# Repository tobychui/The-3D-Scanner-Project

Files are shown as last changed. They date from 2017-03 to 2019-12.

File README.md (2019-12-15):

# Low-Cost-3D-Sanner-Project
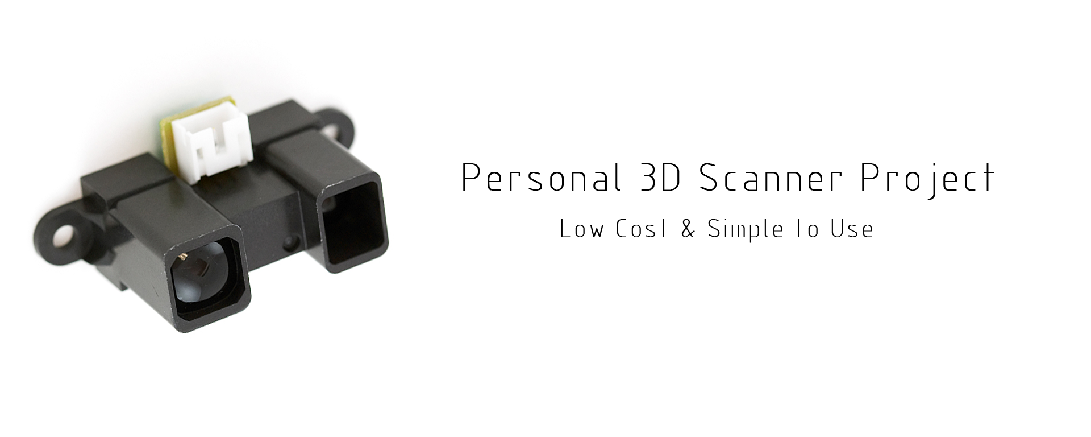
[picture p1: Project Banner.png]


This repo contains all the developmental data of creating a low cost 3D scanner with Arduino. Remember to read README before start building your own one as not all of the version will works.

* Each edition of the 3D Scanner might contain different license information. If a certain version of the scanner do not include a LICNESE file and/or information, the license in this directory (i.e. GNU License) will be used.

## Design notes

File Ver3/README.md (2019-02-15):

# Budget 3D Scanner Version 3

### Introduction
This is another 3D Scanner built with Arduino and Distance Sensor. Different from the other versions before, this version has a modular design and you can mount different type of sensor on the moving platform. 

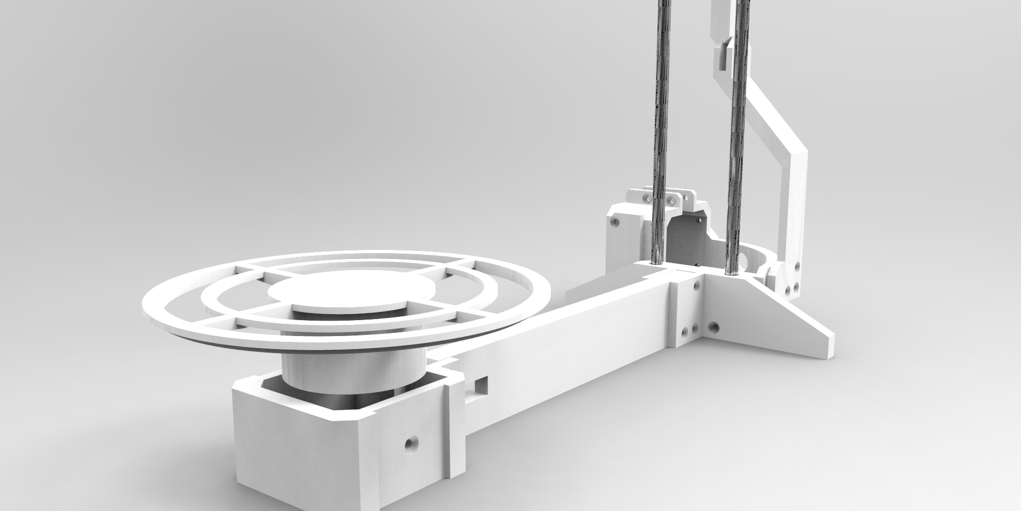
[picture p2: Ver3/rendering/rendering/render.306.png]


### How it works
There are two stepper motors in this device. One used for the platform rotation and one for movint the scanning platform up and down. The rotating platform will represent (and scan) the x / y location of the object while the another stepper will manage the sensor in z direction.

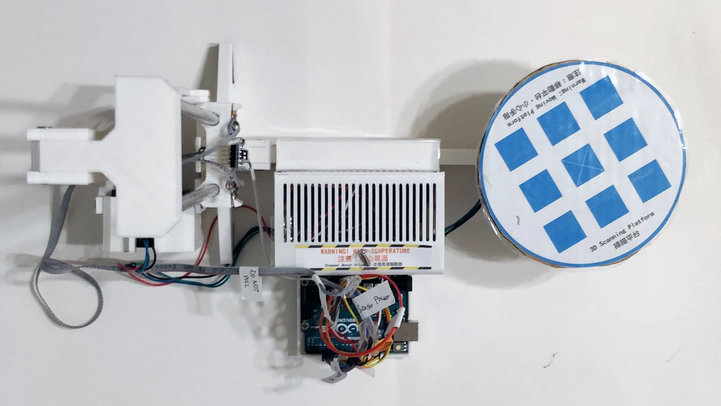
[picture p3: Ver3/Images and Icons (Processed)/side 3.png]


### Instllation & Build
1. 3D Printed all parts from the 3D Model folder. If the parts name is followed by a version number (e.g. parts ver2.stl), use the latest version instead.
2. Prepare the screws needed (All of them are M3 screws either M3 * 5, M3 * 10 or M3 * 20),screw in every screw holes on the 3D model as all of them are necessary.
3. Build the pully guider and glue the pully system in place to the body of the scanner with super glue
4. Install the end stop at the bottom of the devices where next to the bottom pully.
5. Flash in the Arduino code. Use ver 2.2 if you are using VL53L1X ToF Sensor or the infra edition if you are using SHARP IR Sensors
6. Insert all the stepper motor pins to the stepper driver (L298 * 2), and connect the stepper driver to the Arduino pins (4,5,6,7 and 8,9,10,11). Connect the ToF Sensor to SDA and SCL pins or the IR sensor to the A0 pins. End stop should be installed on Pin 12 and PULL LOW with a 10K Ohm resistor.
7. Plug in the power and do a test run. If everything is doing right, you can now install the stepper motors into the scanner body.
8. Use some imagination of anything didn't fits right :)

More details and scan results can be fnd in "Budget 3D Scanner Project.pdf" and operation video "quickdemo.mp4"

### Disclaimer
This project is developed by Toby (Me) and Andy, in which Andy was the guy who wrote the pos-processing scripts.
See his repo here:

<a href="https://github.com/tamyiuchau/Budget3dPrinter">https://github.com/tamyiuchau/Budget3dPrinter</a>

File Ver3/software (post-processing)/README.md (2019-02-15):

# Budget3dPrinter
This is a cheap low cost and might be kind of accurate 3D scanner instead of a printer

Yes, the title is fake. Same as the cake.

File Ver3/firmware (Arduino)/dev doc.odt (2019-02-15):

Budget 3D Scanner Operation Procedures and Documentation
Written by Toby Chui 2/2/2019, Corresponding Firmware: scanner_firmware_2.2

Introduction

This is a build for a low budget 3D scanner with ToF Sensor and Arduino UNO powered by dual 2.8V 200 steps per rev (1.8 degree) stepper motor driven with dual stepper motors. The driving methods and operating procedures is listed below.

Operating Procedures

1. Stick the object that you want to scan onto the platform with double sided tape
2. Plug in the USB cable for the Arduino Serial output to your PC
3. Start serial monitor / Python – Serial capture software
4. Power on the devices. The light blue LED should light up inside the enclosure
5. Run “G95”, wait for the scanner to reach its top position
6. Run “G97” when you place your hand in front of the scanner at a position > 6cm and < 20 cm. Check if the sensor return any value that is larger than 0. If not, continue step 7; otherwise go to step 8
7. Move around the “Sensor Power” wire. Press the restart button on the Arduino and repeat step 5
8. Run “G28”, wait for the sensor head reaching the bottom. If the motor is still running get stuck at the bottom, make sure the sensor wire is not blocking the contact between the head block and the micro switch below.
9. Now, it is ready to start scanning. Enter “G93” to start scanning. Scanning return value with format (h,r,d) where h is height in steps, r is rotation in steps, d is distance in mm.
10. Wait for the scanning process finish.
11. Power off the device after use to prevent heat accumulation in stepper driver

All Supported G-Code command

G28 → Sensor Home (Default)

G93 → Start Scanning

G94 → Calibration (Please put the calibration board in the center position of the scanner platform before using this command)

G95 → Sensor Home (Top), Moving the sensor to the top value preset)

G96 → Platform Check (Perform a full rotation as speed 60rpm)

G97 → Sensor Read (Get the current value from sensor)

DEFAULT → reply with “[info] Echo: <your command here>”

Firmware written for Budget 3D Scanner Project 2018 – 2019

DO NOT DISCLOSE BEFORE 15/2/2019

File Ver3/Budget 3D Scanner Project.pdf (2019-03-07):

# Budget 3D Scanner Project

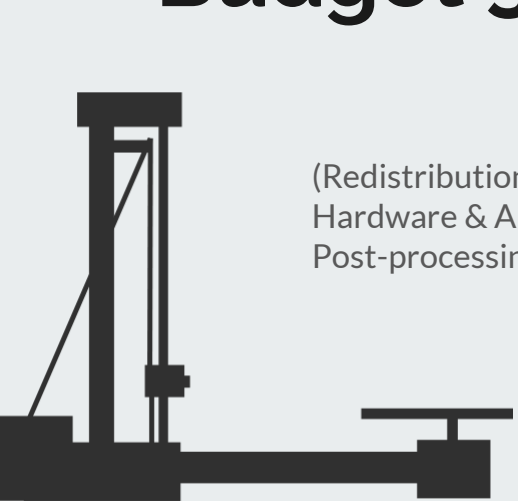
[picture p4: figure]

### (Redistribution Edition - Open Source Project) Hardware & Arduino Programming: Toby Post-processing & Optimization: Andy

# Introduction

- 3D Scanners are kind of expensive right now but it has a wide range of application
- We want to make a low cost 3D scanner with ToF Sensor and two stepper motors as Proof of Concept
- Aim as create somewhat observable 3D models from one single sensor by converting the sensor data into point clouds that construct the 3D model

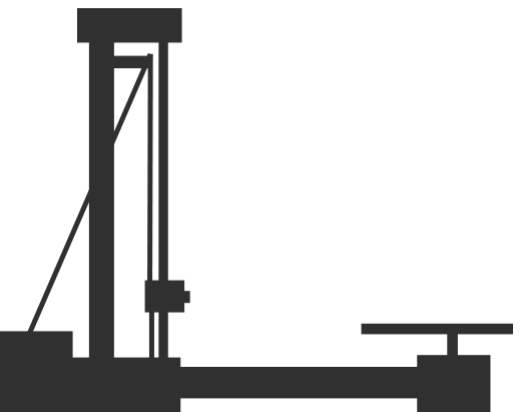
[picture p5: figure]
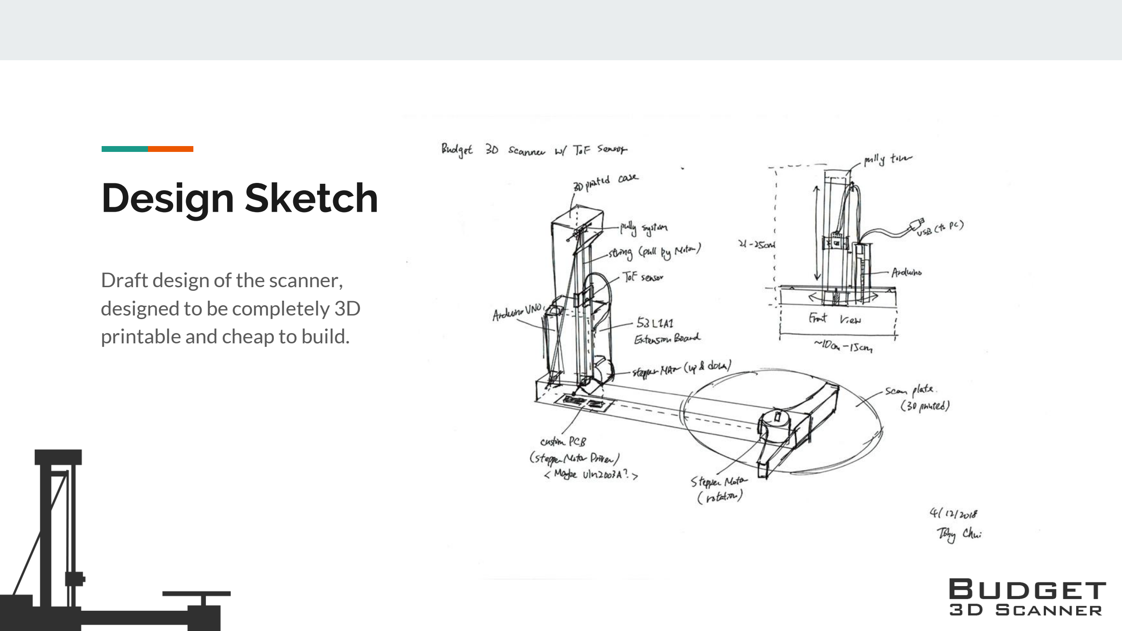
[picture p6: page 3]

# Design Sketch

Draft design of the scanner, designed to be completely 3D printable and cheap to build.

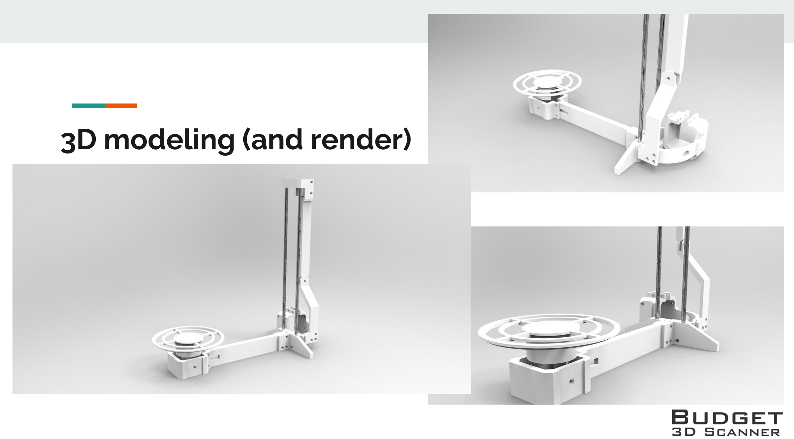
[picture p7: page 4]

# 3D modeling (and render)

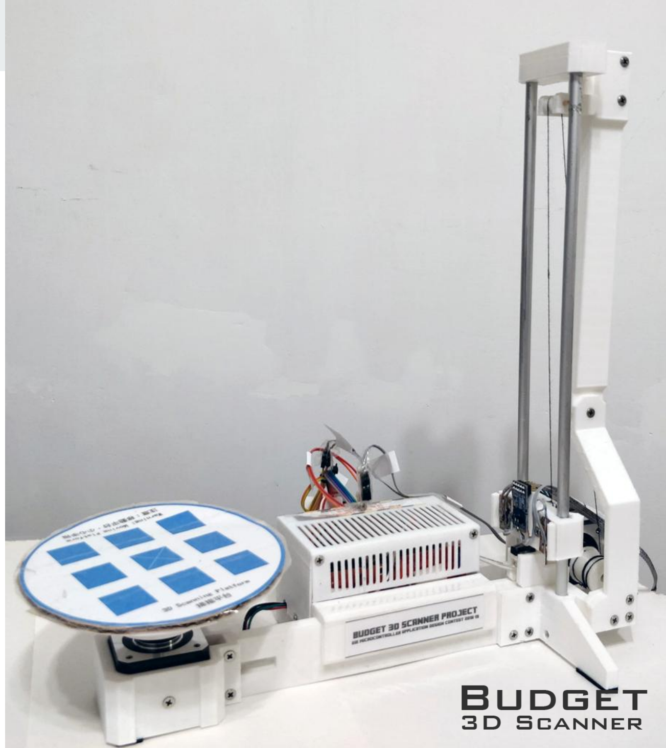
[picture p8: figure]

# Final Product (Scanner)

Specification:

VL53L1X ToF Sensor
(SHARP GP2D12F)
Arduino UNO
2.8V Stepper Motor x2
Many 3D Printed Parts

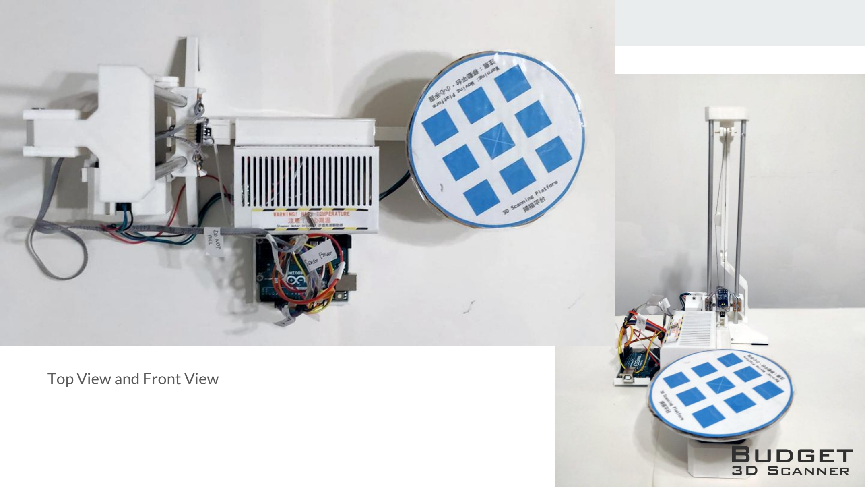
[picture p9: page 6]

Top View and Front View

# Scanner In Action

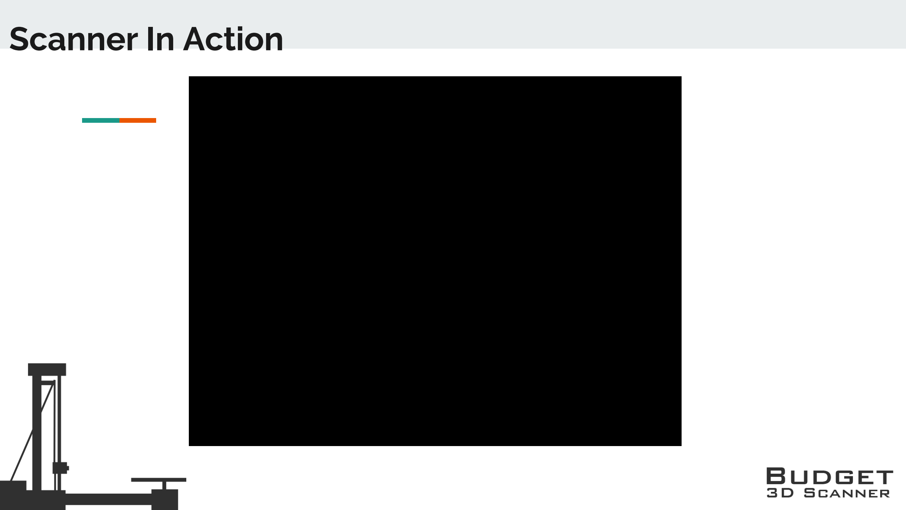
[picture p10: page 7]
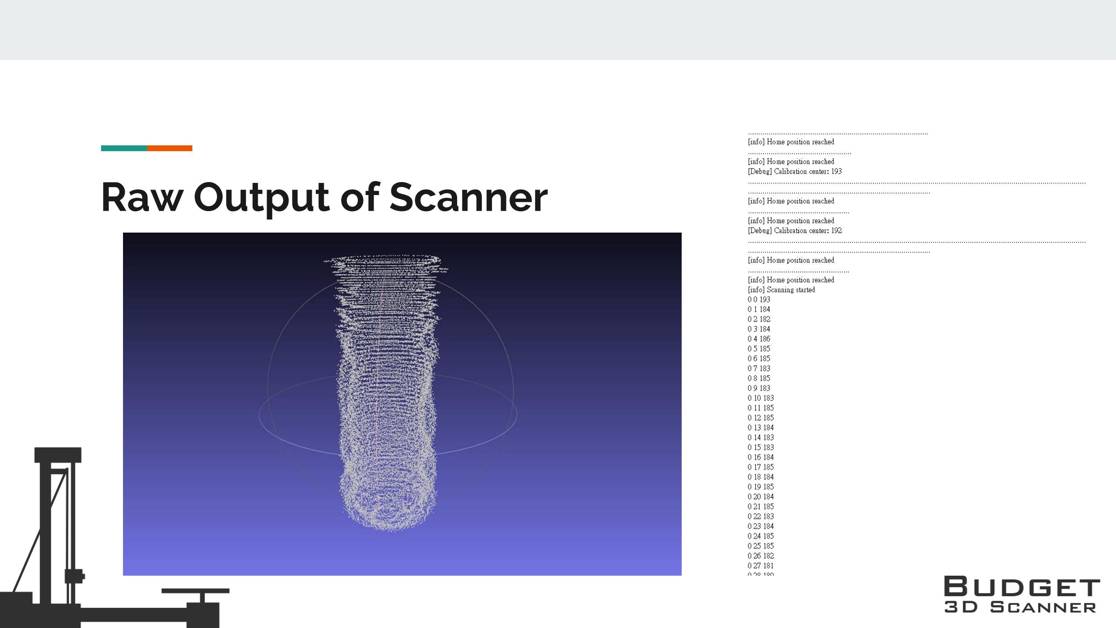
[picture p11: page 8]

# Raw Output of Scanner

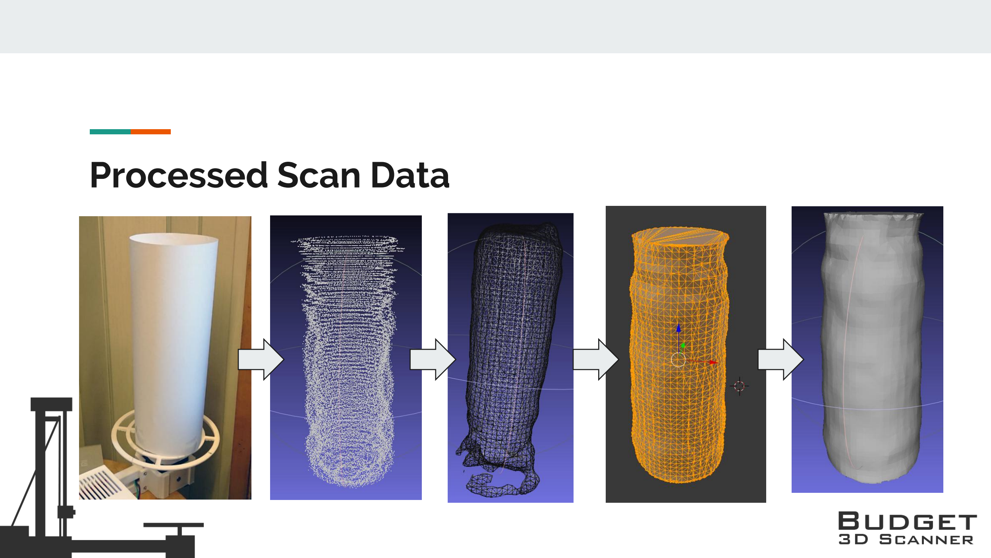
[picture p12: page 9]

# Processed Scan Data

# Calibration formula deduction

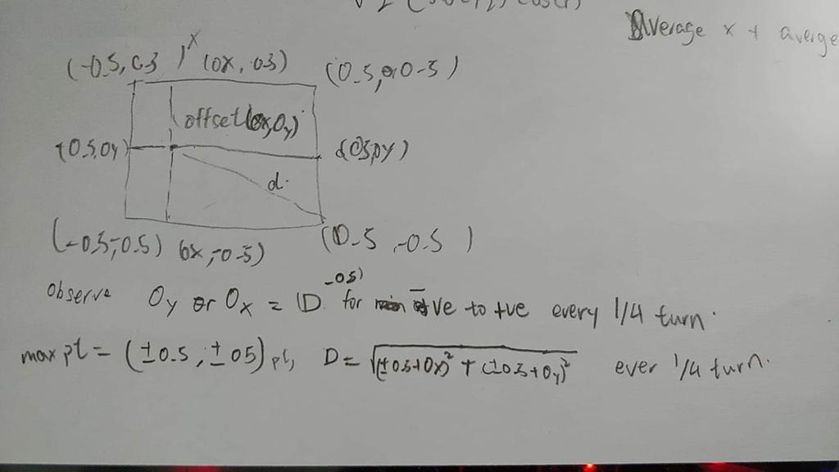
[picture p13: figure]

# Assumptions

The placement of calibration box is off centered → unknow center point

The height ratio is straight forward: (top - bottom )/ steps

The depth is the complicated part.

x = depth * sin(theta), y = depth * cos (theta)

But hey the box is off centered and we don’t know any of x and y and theta!

# Derive a function that link everything together

D =

(side /2 + Ox) / sin(theta+offset) | 0<= theta <=pi/2
(side /2 - Oy) / sin(theta+offset) | pi/2<= theta <= pi
(side /2 - Ox) / sin(theta+offset) | pi <= theta <= 3pi/2
(side /2 + Oy) / sin(theta+offset) | 3pi/2<= theta <= 2pi

Too complicate, we can go with only local minimum : (sin(theta)=1)

(Ox,Oy)

| D

# Going through the DARKNESS of calculus

We can eliminate variables using differentiation

d D/ dr = 0 ← solve r and left with 1 unknown

can be approximated by D(r+Δr)-D(r)/Δr

Also need to reject d^2 D/ dr > 0 (local max)

# It gots clear at this point

at each local minimum

d_min ± (Ox or Oy) = depth (measured by sensor)

One more trick

let Oy >= Ox

d - Oy <= d - Ox <= d + Ox <= d + Oy

cancel out Oy, done

(Ox,Oy)

| D

# Cost Summary

Item Name | Amount / Units | Cost (in HKD) | Remarks
3D Printed Parts | Around 700g | $84 | Estimated Material Cost
VL53L1X | 1 | $336 | Replaced with Infrared sensor due to accident
GP2D12 | 1 | $78 | SHARP Infrared sensor
L298N | 2 | $35.3 x 2
Arduino UNO | 1 | $180.52

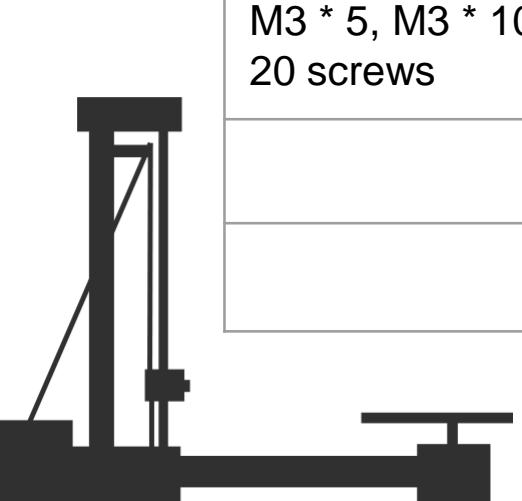
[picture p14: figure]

M3 * 5, M3 * 10, M3 * 20 screws | >20 | Neglectable
| | Total (with ToF) | $671.12
| | Total (with IR) | $413.12

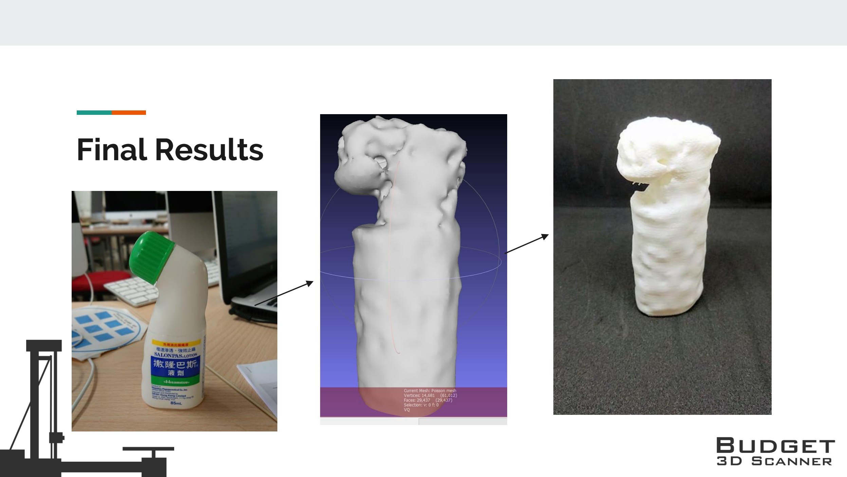
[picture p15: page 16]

# Final Results

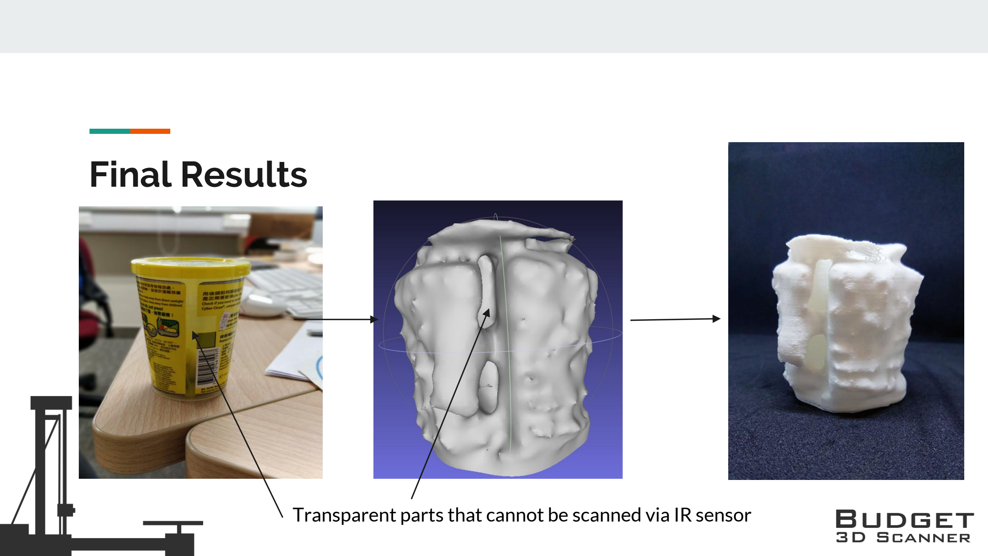
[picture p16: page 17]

# Final Results

Transparent parts that cannot be scanned via IR sensor

# Future Development

- Use dual sensor mode with Ultrasound Sensor to reduce error from reflection and transparent material
- Improve post-processing and scanning accuracy (This ToF Sensor is not the best one to suit this kind of application)
- 3D Copying Machine! (Scanner directly output gcode for 3D printer to print at the same time)

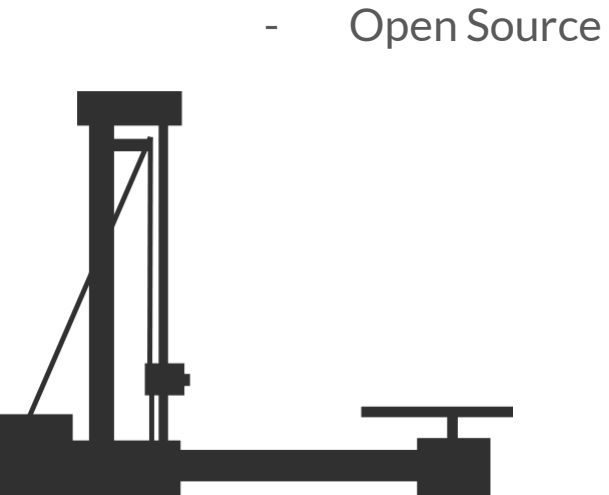
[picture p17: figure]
- Open Source
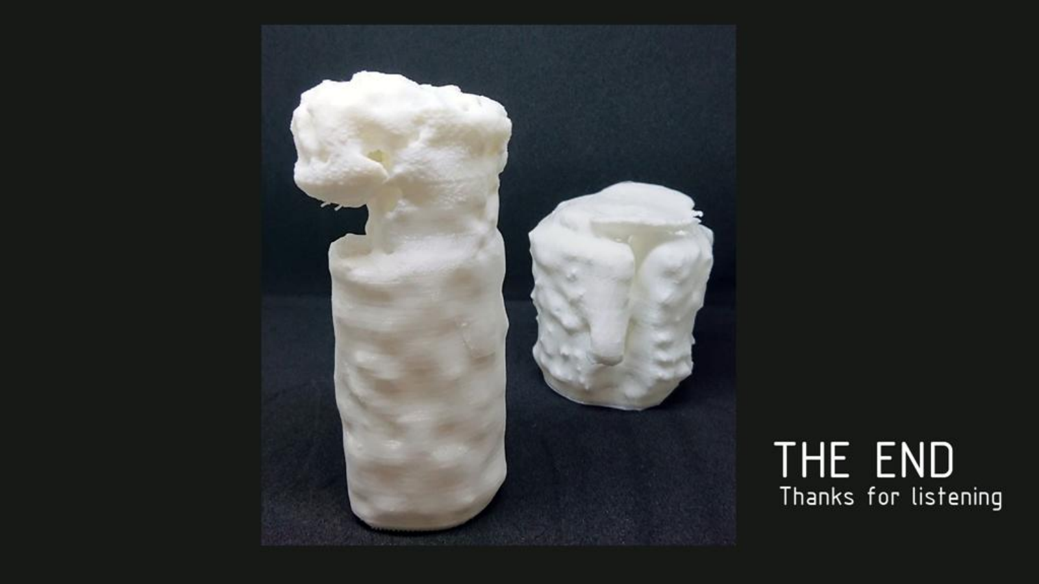
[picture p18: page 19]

# Thank you

# Reference and CopyRight

All the content in this powerpoint is licensed under IMUS License (Somewhat the same as MIT License with some extra about hardware), All Right Reserved.
You can freely distribute this powerpoint with the following restriction
- No Commercial Uses
- No charge / fees should be involved when distributing this powerpoint and related files inside this project
- Toby and Andy (Author of this project) has all right towards this project and all project material. The author will not bear any responsibility to the safety, workability, accuracy or other technical or safety related issue regarding this machine.
- Ask for permission for usage if you are using this project (and its material) for any purposes except educational and personal uses purpose.

Visit https://www.facebook.com/ImusLaboratory for more information

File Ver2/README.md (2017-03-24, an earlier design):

# 3D Scanner Ver 2

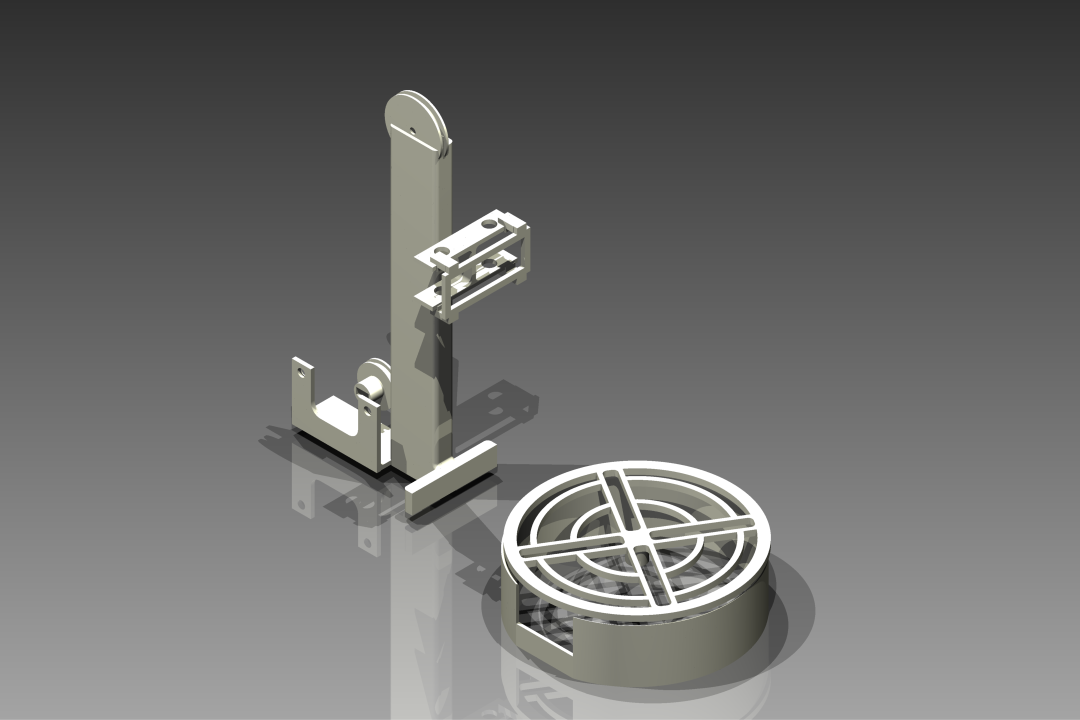
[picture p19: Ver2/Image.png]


This version is the 1st succeed version of the low cost 3D printer Project with ultrasound Sensor.
For the tutorial to make this scanner, please visit my instructable here:

https://www.instructables.com/id/Ultra-Low-Cost-3D-Scanner/

## Simple Instruction
To use this scanner, you have to build the 3D scanner itself with the 3d models provided here
Next, uplaod the Arduino sketch onto your arduino nano (Arduino UNO will work just fine)
Run the code using Arduino IDE Serial, copy all the returned information into the software "Length to 3D coordinate Scanner Data Convertor"
Convert it from raw information to coordinate data
Copy the exported data and sve them in a text file named "your name here".asc
Open that file in Meshlab for viewing

## How to convert it into stl?
To convert it into stl, you have to import the asc file into Meshlab
From filter, choose Calculate Normal with a sample rate 500 -1000 for the best results.
Next, also from the filter section, select Possion Surface Reconstruction (Or the reconstruction function with the name "Possion" in it if you are using newer version)
Click ok, wait for it and export the stl mesh as usual.

## How can I improve the accuracy of reading?
You can add one more line in the Arduino code to do the following things
1. For each point, scan multiple times and get the mean value of the reading
2. After reading a point, rotate smaller degree for more points (vertex) in 3D model
3. Change the Ultrasoud Sensor into Infrared Sensor (which someone already did) or laser distance sensor (which is very expensive)
4. Don't put in any soft item for scanning (e.g. cloth like materials, sponge, or things with a lot of holes)

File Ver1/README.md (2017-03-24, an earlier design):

# Version 1
This version of 3D Scanner make use of two stepper motors and one Ultrasound Sensor to scan the object in front of the scanner.
Please ** DO NOT USE THIS VERSION ** unless you are using those commercial printer with super high accuracy. 

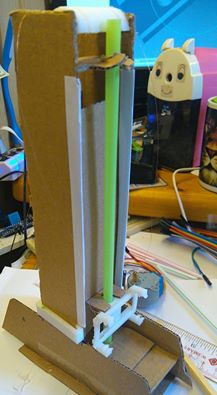
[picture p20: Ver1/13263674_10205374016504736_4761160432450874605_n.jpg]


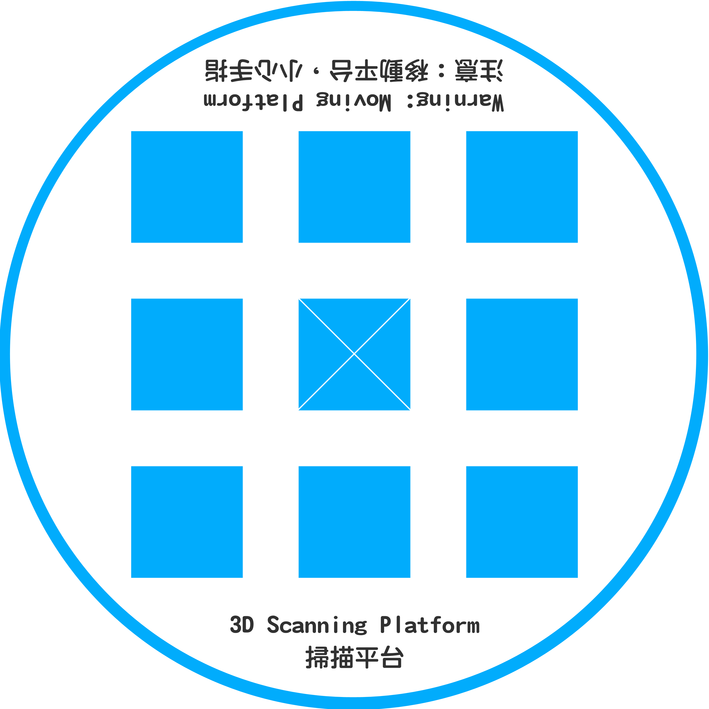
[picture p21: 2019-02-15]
Ver3/3D Models/platform and labels/platform label.png

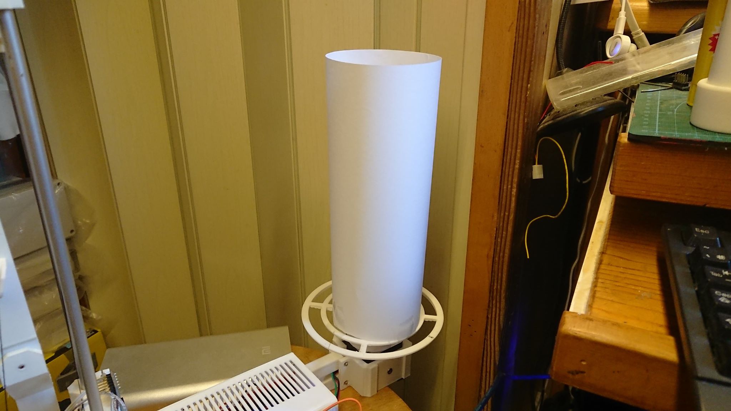
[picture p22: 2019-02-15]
Ver3/trial-scan data/post-processing/50949553_391221454968924_2815259296256753664_n.jpg

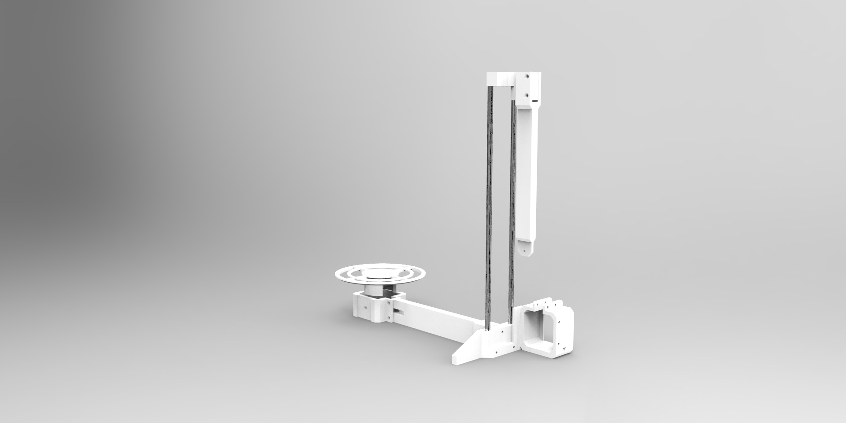
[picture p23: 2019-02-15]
Ver3/rendering/rendering/render.301.png

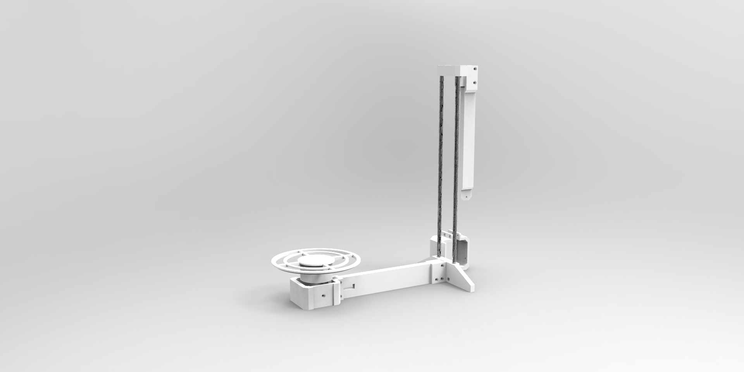
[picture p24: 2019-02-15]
Ver3/rendering/rendering/render.300.png

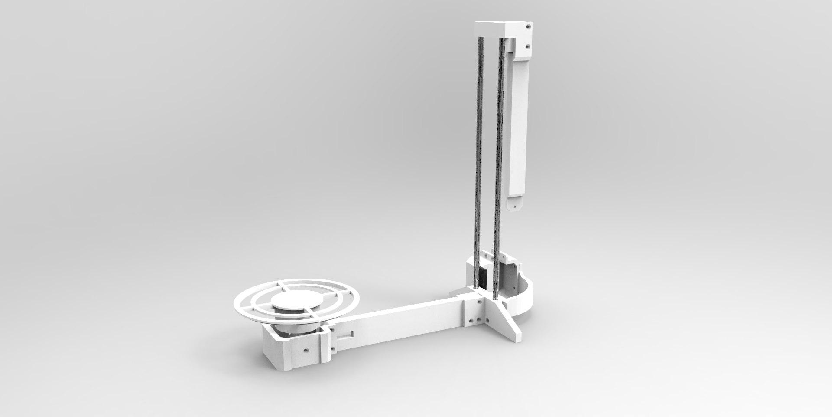
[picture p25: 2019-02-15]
Ver3/rendering/rendering/render.302.png

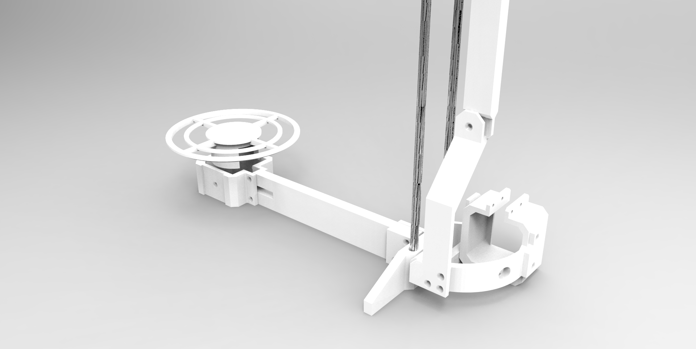
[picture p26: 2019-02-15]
Ver3/rendering/rendering/render.305.png

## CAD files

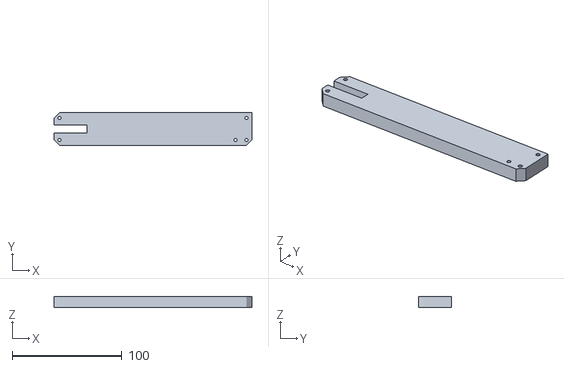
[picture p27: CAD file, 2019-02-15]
Ver3/3D Models/Connection Bar.stl
180.0 x 30.0 x 10.0

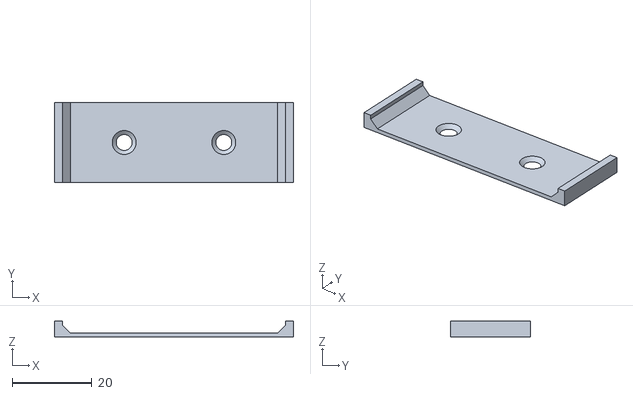
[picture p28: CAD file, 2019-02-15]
Ver3/3D Models/scanner head/head mount.stl
60.0 x 20.0 x 4.00

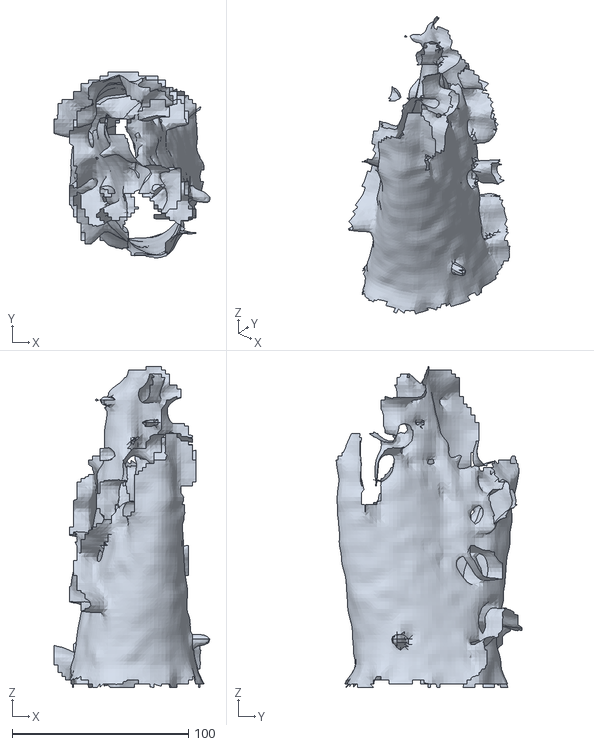
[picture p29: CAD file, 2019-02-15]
Ver3/trial-scan data/plymcout.ply
88.4 x 105.6 x 182.1

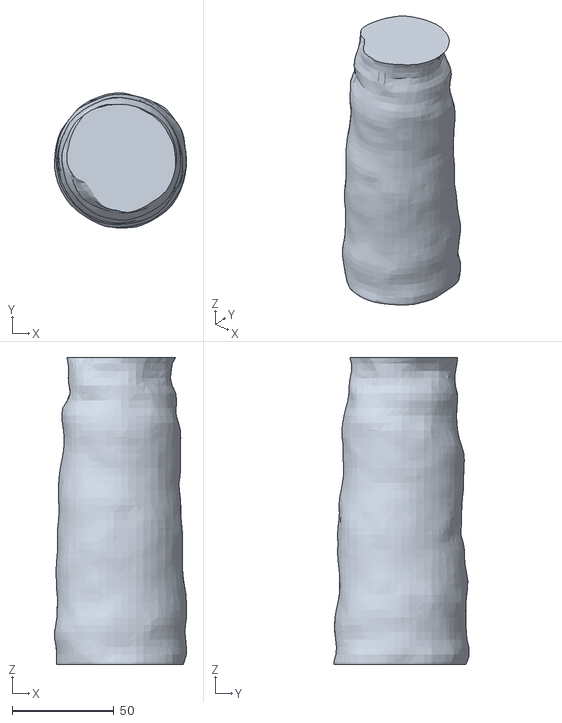
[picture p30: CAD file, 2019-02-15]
Ver3/trial-scan data/post-processing/scan log (after cropping).stl
65.0 x 66.5 x 150.9

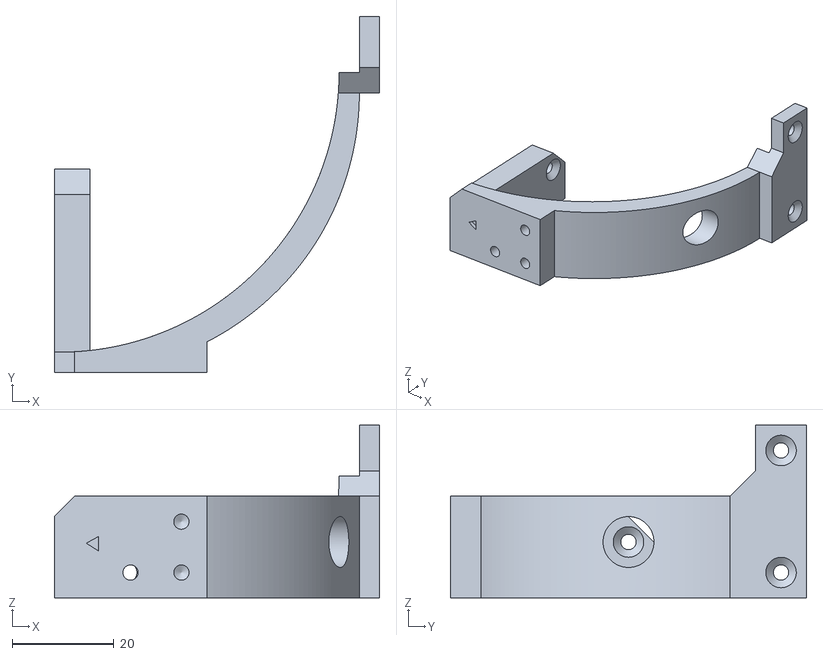
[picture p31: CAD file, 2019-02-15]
Ver3/3D Models/z-stepper support arm.stl
64.0 x 70.0 x 34.0

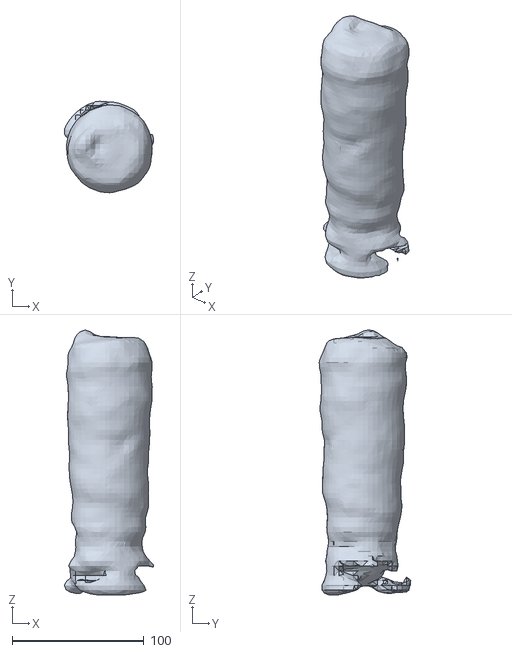
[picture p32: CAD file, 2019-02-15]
Ver3/trial-scan data/post-processing/scan log.stl
67.6 x 69.4 x 200.8

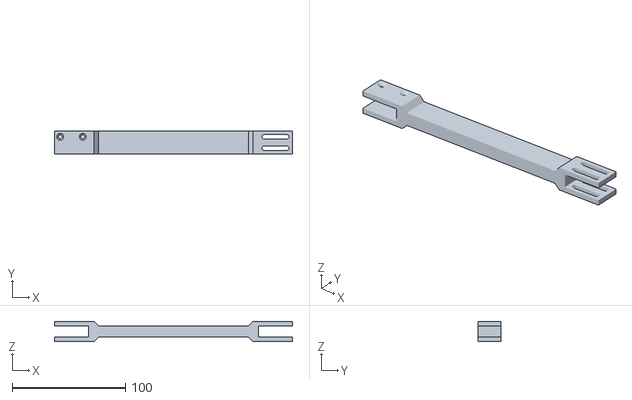
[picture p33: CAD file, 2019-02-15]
Ver3/3D Models/Upper Support beam.stl
210.0 x 20.0 x 18.0

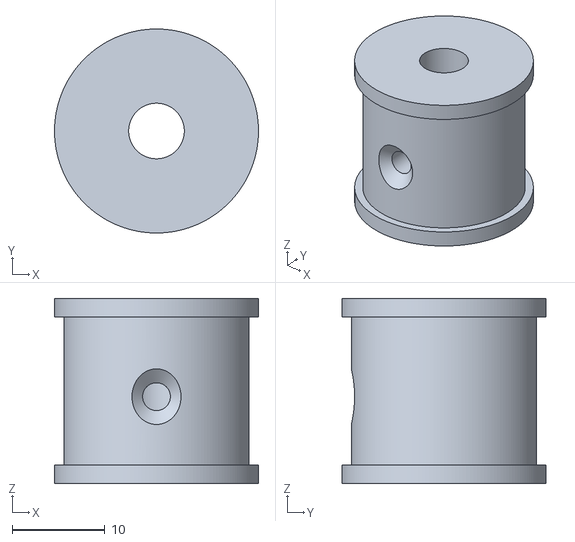
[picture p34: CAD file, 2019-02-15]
Ver3/3D Models/z-col pully sys/bearing v3.stl
22.0 x 22.0 x 20.0

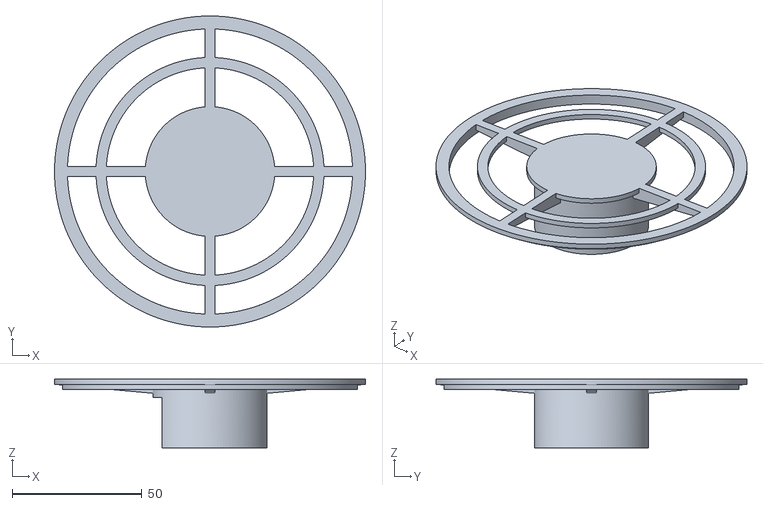
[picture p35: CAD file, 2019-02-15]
Ver3/3D Models/rotating platform.stl
120.0 x 120.0 x 26.5

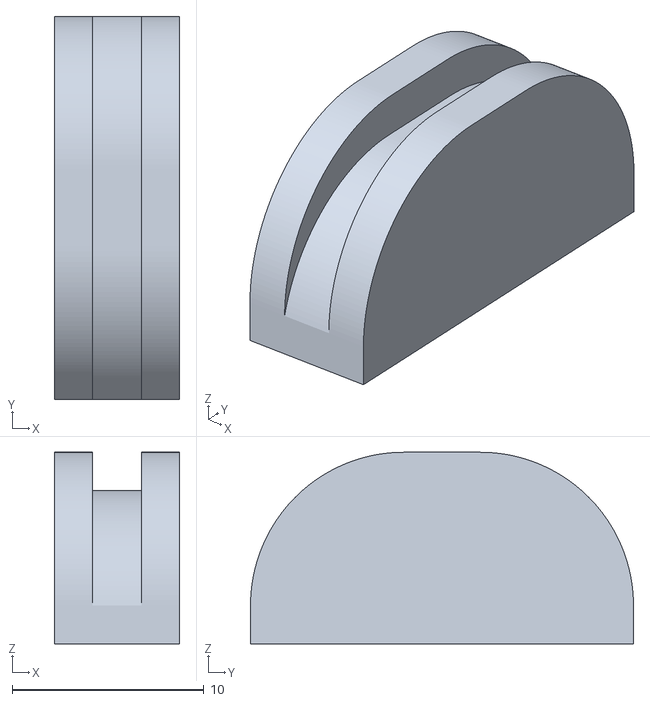
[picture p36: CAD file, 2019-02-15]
Ver3/3D Models/z-col pully sys/String Tightener.stl
6.55 x 20.0 x 10.0

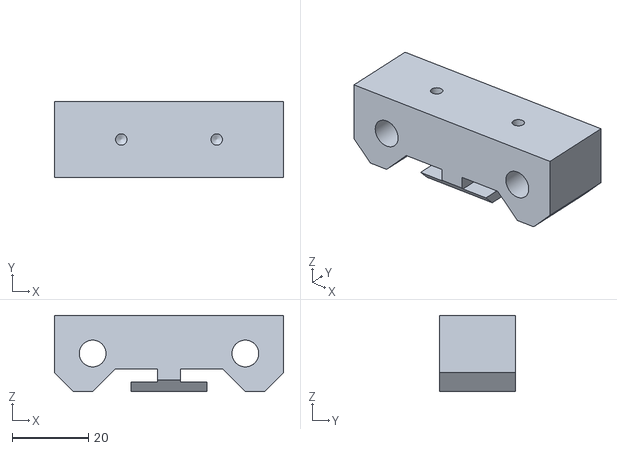
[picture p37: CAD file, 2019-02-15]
Ver3/3D Models/z-col pully sys/Moving block.stl
60.0 x 20.0 x 20.0

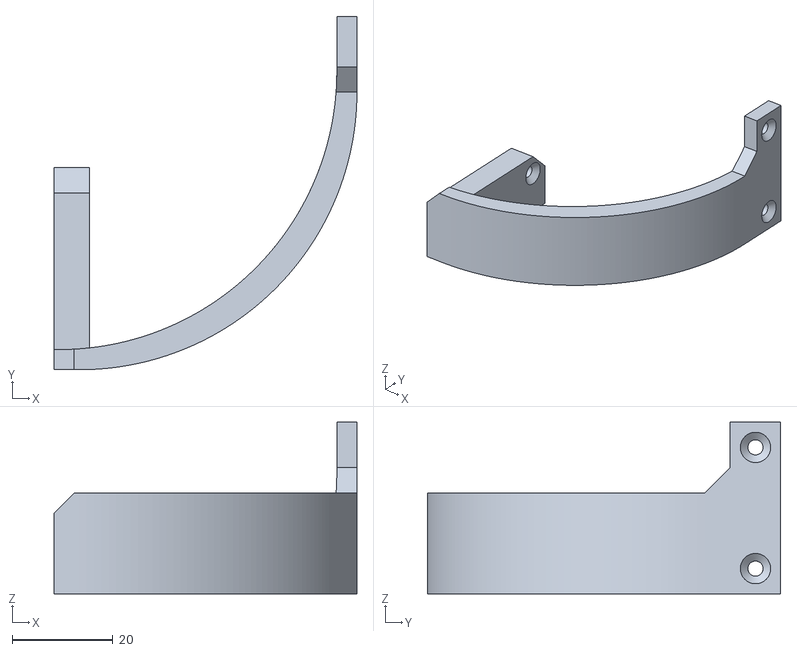
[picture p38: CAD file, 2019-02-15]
Ver3/3D Models/z-stepper support arm test2.stl
60.0 x 70.0 x 34.0

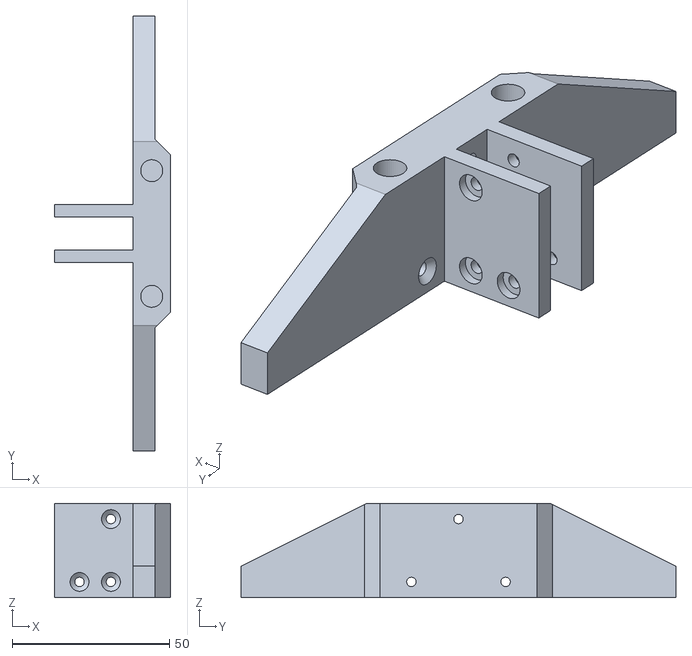
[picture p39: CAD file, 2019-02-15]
Ver3/3D Models/Col support beam.stl
37.0 x 138.5 x 30.0

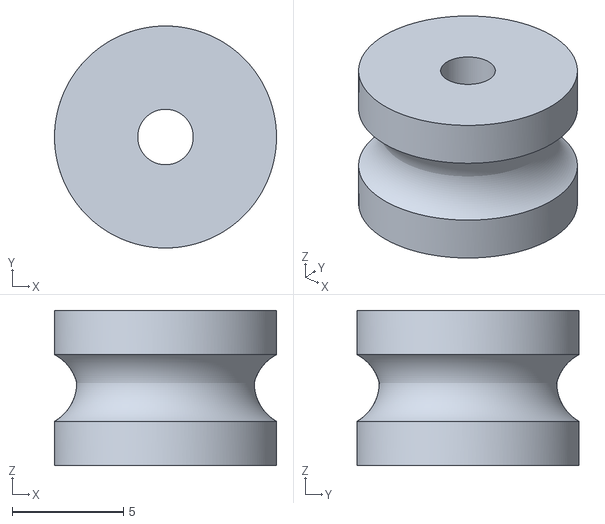
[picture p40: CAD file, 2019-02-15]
Ver3/3D Models/z-col pully sys/pully.stl
10.0 x 10.00 x 7.00

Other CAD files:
Ver3/trial-scan data/post-processing/scan log (subdivided).stl
Ver3/trial-scan data/post-processing/scan log (final).stl
Ver3/3D Models/col support base.stl
Ver3/3D Models/z-col pully sys/Bottom pully rack.stl
Ver1/Roller ver2.ipt
Ver1/Roller ver2.stl
Ver1/Roller.ipt
Ver1/Roller.stl
Ver1/Side Grapper.ipt
Ver1/Side Grapper.stl
Ver1/Slider.ipt
Ver1/Slider.stl
Ver1/Top Pully.ipt
Ver1/Top Pully.stl
Ver1/Up go er.ipt
Ver1/Up go er.stl
Ver1/baser.ipt
Ver1/baser.stl
Ver2/Cable Sliding Assistor.ipt
Ver2/Cable Sliding Assistor.stl
Ver2/Main Stand.ipt
Ver2/Main Stand.stl
Ver2/OldVersions/Slider.0001.ipt
Ver2/OldVersions/Top Holder.0001.ipt
Ver2/Pulling Stepper Pully.ipt
Ver2/Pulling Stepper Pully.stl
Ver2/Pully Top.ipt
Ver2/Pully Top.stl
Ver2/Scanning Disk.ipt
Ver2/Scanning Disk.stl
Ver2/Slider ver2.ipt
Ver2/Slider ver2.stl
Ver2/Slider.ipt
Ver2/Slider.stl
Ver2/Stpper Wheel 2.ipt
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

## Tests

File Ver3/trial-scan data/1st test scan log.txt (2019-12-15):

[info] Budget 3D Printer Control System
[info] Starting I2C connectons...
[info] Initializing VL53L1X sensor...
[info] VL53L1X initialized
[OK] Ready!
...................................................................................................................................................................................................................................
[info] Home position reached
[info] Scanning started
0 0 170
0 5 170
0 10 144
0 15 144
0 20 148
0 25 148
0 30 142
0 35 142
0 40 137
0 45 137
0 50 132
0 55 132
0 60 110
0 65 110
0 70 134
0 75 134
0 80 140
0 85 140
0 90 143
0 95 143
0 100 117
0 105 117
0 110 121
0 115 121
0 120 160
0 125 160
0 130 146
0 135 146
0 140 138
0 145 138
0 150 136
0 155 136
0 160 154
0 165 154
0 170 132
0 175 132
0 180 141
0 185 141
0 190 145
0 195 145
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
[info] Scanning Ended
...........................................................................................................................................................................................................................................................................................................................................................................................................................................................................................................................................................................................................................................................................
[info] Home position reached

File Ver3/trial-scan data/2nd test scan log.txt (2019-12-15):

0 0 232
0 1 232
0 2 232
0 3 232
0 4 232
0 5 232
0 6 157
0 7 157
0 8 157
0 9 157
0 10 157
0 11 157
0 12 162
0 13 162
0 14 162
0 15 162
0 16 162
0 17 162
0 18 163
0 19 163
0 20 163
0 21 163
0 22 163
0 23 163
0 24 163
0 25 163
0 26 163
0 27 163
0 28 163
0 29 163
0 30 158
0 31 158
0 32 158
0 33 158
0 34 158
0 35 158
0 36 165
0 37 165
0 38 165
0 39 165
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

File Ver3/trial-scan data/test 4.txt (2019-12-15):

[info] Budget 3D Printer Control System
[info] Starting I2C connectons...
[info] Initializing VL53L1X sensor...
[info] VL53L1X initialized
[OK] Ready!
..................................................
[info] Home position reached
[info] Scanning started
0 0 2400
0 1 2400
0 2 143
0 3 143
0 4 142
0 5 142
0 6 144
0 7 144
0 8 142
0 9 142
0 10 142
0 11 142
0 12 141
0 13 141
0 14 142
0 15 142
0 16 140
0 17 140
0 18 139
0 19 139
0 20 139
0 21 139
0 22 141
0 23 141
0 24 138
0 25 138
0 26 141
0 27 141
0 28 141
0 29 141
0 30 137
0 31 137
0 32 136
0 33 136
0 34 135
0 35 135
0 36 136
0 37 136
0 38 134
0 39 134
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

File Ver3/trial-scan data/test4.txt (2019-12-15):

0 0 2467
0 1 2467
0 2 2467
0 3 144
0 4 144
0 5 144
0 6 144
0 7 144
0 8 144
0 9 144
0 10 144
0 11 144
0 12 142
0 13 142
0 14 142
0 15 143
0 16 143
0 17 143
0 18 140
0 19 140
0 20 140
0 21 141
0 22 141
0 23 141
0 24 142
0 25 142
0 26 142
0 27 139
0 28 139
0 29 139
0 30 141
0 31 141
0 32 141
0 33 140
0 34 140
0 35 140
0 36 141
0 37 141
0 38 141
0 39 140
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

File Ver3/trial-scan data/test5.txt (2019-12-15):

[info] Budget 3D Printer Control System
[info] Starting I2C connectons...
[info] Initializing VL53L1X sensor...
[info] VL53L1X initialized
[OK] Ready!
..................................................
[info] Home position reached
[info] Scanning started
0 0 2505
0 1 154
0 2 156
0 3 155
0 4 154
0 5 154
0 6 156
0 7 154
0 8 154
0 9 153
0 10 154
0 11 153
0 12 152
0 13 152
0 14 152
0 15 150
0 16 150
0 17 152
0 18 149
0 19 151
0 20 151
0 21 150
0 22 150
0 23 147
0 24 149
0 25 147
0 26 149
0 27 148
0 28 149
0 29 149
0 30 147
0 31 151
0 32 148
0 33 147
0 34 146
0 35 149
0 36 148
0 37 148
0 38 151
0 39 149
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

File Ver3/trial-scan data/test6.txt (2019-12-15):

130 39 294
[info] Budget 3D Printer Control System
[info] Starting I2C connectons...
[info] Initializing VL53L1X sensor...
[info] VL53L1X initialized
[OK] Ready!
.....................................................................................................................................................................................
[info] Home position reached
[Debug] Calibration center: 1448
..........................................................................................................................................................................................................................................................
[info] Home position reached
..................................................
[info] Home position reached
[Debug] Calibration center: 192
..........................................................................................................................................................................................................................................................
[info] Home position reached
...................................................
[info] Home position reached
[Debug] Calibration center: 192
.........................................................................................................................................................................................................................................................
[info] Home position reached
[Debug] Rotating platform for a full revolution...
[Debug] Moving scanner to top position...
..........................................................................................................................................................................................................................................................................................................................
[info] Home position reached
[info] Homing...
............................................................................................................................................................................................................................................................................................................................................................................................................................................................................................................................................................................................................................................................................
[info] Home position reached
[Debug] Moving scanner to top position...
................................................
[info] Home position reached
[Debug] Moving scanner to top position...
...........................................................................................................................................................................................................................................................................................................................................................................................................................................................................................................................................................................................................................................................................
[info] Home position reached
[info] Homing...
..........................................................................................................................................................................................................................................................................................................................................................................................................................................................................................................................................................................................................................................................................
[info] Home position reached
[Debug] Moving scanner to top position...
..................................................
[info] Home position reached
[Debug] Moving scanner to top position...
..........................................................................................................................................................................................................................................................................................................................................................................................................................................................................................................................................................................................................................................................................
[info] Home position reached
[Debug] Moving scanner to top position...
.........................................................................................................................................................................................................................................................................................................................................................................................................................................................................................................................................................................................................................................................................
[info] Home position reached
[info] Homing...
..........................................................................................................................................................................................................................................................................................................................................................................................................................................................................................................................................................................................................................................................................
[info] Home position reached
[Debug] Rotating platform for a full revolution...
[Debug] Rotating platform for a full revolution...
[Debug] Checking sensor value...
[Measurement] #0 : 191
[Measurement] #1 : 191
[Measurement] #2 : 191
[Measurement] #3 : 191
[Debug] Calibration center: 191
....................................................................................................................................................................................
[info] Home position reached
[Debug] Calibration center: 235
..........................................................................................................................................................................................................................................................
[info] Home position reached
..................................................
[info] Home position reached
[Debug] Calibration center: 193
...........................................................................................................................................................................................................................................................
[info] Home position reached
.................................................
[info] Home position reached
[Debug] Calibration center: 192
...........................................................................................................................................................................................................................................................
[info] Home position reached
.................................................
[info] Home position reached
[info] Scanning started
0 0 193
0 1 184
0 2 182
0 3 184
0 4 186
0 5 185
0 6 185
0 7 183
0 8 185
0 9 183
0 10 183
0 11 185
0 12 185
0 13 184
0 14 183
0 15 183
0 16 184
0 17 185
0 18 184
0 19 185
0 20 184
0 21 185
0 22 183
0 23 184
0 24 185
0 25 185
0 26 182
0 27 181
0 28 180
0 29 182
0 30 182
0 31 182
0 32 183
0 33 183
0 34 182
0 35 183
0 36 180
0 37 182
0 38 182
0 39 183
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

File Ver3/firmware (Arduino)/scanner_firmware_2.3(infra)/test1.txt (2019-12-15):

[info] Budget 3D Printer Control System
[info] Starting I2C connectons...
[info] Initializing VL53L1X sensor...
[OK] Ready!
........................................................................................................................................................................................................................................................................................................................................................................................................................................................................................................................................................................................................................................................................
[info] Home position reached
[Debug] Calibration center: 168.19
.........................................................................................................................................................................................................................................................
[info] Home position reached
.................................................
[info] Home position reached
[info] Scanning started
0 0 531.65
0 1 520.17
0 2 515.74
0 3 548.29
0 4 570.13
0 5 550.17
0 6 551.49
0 7 557.46
0 8 519.51
0 9 531.92
0 10 547.58
0 11 501.07
0 12 522.75
0 13 553.02
0 14 537.78
0 15 564.95
0 16 537.92
0 17 496.90
0 18 542.86
0 19 529.65
0 20 566.54
0 21 534.83
0 22 557.10
0 23 519.80
0 24 506.04
0 25 532.22
0 26 570.20
0 27 563.61
0 28 575.66
0 29 513.05
0 30 574.22
0 31 523.67
0 32 500.03
0 33 526.52
0 34 545.34
0 35 535.84
0 36 523.89
0 37 543.97
0 38 575.10
0 39 521.18
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

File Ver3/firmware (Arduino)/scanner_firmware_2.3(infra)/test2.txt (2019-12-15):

[info] Budget 3D Printer Control System
[info] Starting I2C connectons...
[info] Initializing VL53L1X sensor...
[OK] Ready!
..............................................................................................
[info] Home position reached
[info] Scanning started
0 0 178.72
0 1 174.95
0 2 169.04
0 3 172.60
0 4 165.57
0 5 172.59
0 6 166.80
0 7 172.10
0 8 168.33
0 9 167.12
0 10 169.67
0 11 166.61
0 12 165.21
0 13 171.10
0 14 162.46
0 15 162.46
0 16 163.82
0 17 165.20
0 18 159.33
0 19 165.51
0 20 161.33
0 21 165.82
0 22 158.08
0 23 164.89
0 24 165.08
0 25 163.53
0 26 162.78
0 27 160.40
0 28 158.67
0 29 160.97
0 30 161.42
0 31 157.03
0 32 161.83
0 33 164.59
0 34 166.65
0 35 159.97
0 36 159.88
0 37 160.95
0 38 159.22
0 39 155.62
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

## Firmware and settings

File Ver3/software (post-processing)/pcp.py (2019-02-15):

import serial
import struct
import math
import os
#Constants
R_MAX = 200 #max rotation
R_MIN = 0
R_STEP = 1
R_RATIO = 2*math.pi /(R_MAX -R_MIN)# radian
H_MAX = 600
H_MIN = 0
H_STEP = 1
H_RATIO = (250-62)/(H_MAX-H_MIN) # heigh per step
D_MAX = 190
D_MIN = 0
D_RATIO = 1 # 1mm
#Formating
TX_FMT = 'LL'
RX_FMT = 'LLL' # l: signed long, L: unsigned long, f float
RX_L = struct.calcsize(RX_FMT)
DEFAULT_FILE = "./test2-1.txt"

def calculate(r,h,d,downangle = 0):
    d = (d-D_MAX)
    dd = d*D_RATIO
    rr = r*R_RATIO
    x = dd*math.cos(rr)
    y = dd*math.sin(rr)
    z = h*H_RATIO-(dd*math.sin(downangle/180*math.pi))
    return x,y,z
def condition(r,h,d):
    return d>D_MIN
def pattern():
    for th in range(H_MIN,H_MAX,H_STEP):
        for tr in range(R_MIN,R_MAX,R_STEP):
            yield th,tr
def main():
    r = b''
    with serial.Serial("COM5",115200,timeout=1) as s:
        print(".")
        p = pattern()
        for th,tr in p:
            s.write(struct.pack  (TX_FMT,tr,th))
            while len(r)<RX_L:
                r += s.read(RX_L)
            print(r)
            (rr,rh,rd) = struct.unpack(RX_FMT,r[:RX_L])
            r = r[RX_L:]
            if condition(rr,rh,rd):
                break
            else:
                yield calculate(rr,rh,rd)
def point_from_file(f = DEFAULT_FILE):
    with open(f,"r") as f:
        for _ in range(13):
            f.readline()
        for i in f:
            try:
                h,r,d = [int(j) for j in i.split()]
                if d>D_MAX or d<1:
                    continue
                yield calculate(r,h,d)
            except Exception as e:
                print(e)
                break
def avg(f = "./test5.txt"):
    ds = []
    with open(f,"r") as f:
        for _ in range(13):
            f.readline()
        for i in f:
            try:
                h,r,d = [int(j) for j in i.split()]
                if d>D_MAX or d<1:
                    continue
                ds.append(d)
                #yield calculate(r,h,d)
            except Exception as e:
                print(e)
                break
    return ds
def tuning(f = DEFAULT_FILE):
    """
    Tuning the scanner by 10cm * 10cm cube
    !!!The number of points of rotation must be a multiple of 2(rotational symetry)!!!
    !!!Assume tuning cube colide with spining center!!!
    """

    """
    Calculation
    
    """
    side = 100 #mm
    p2, p1 = None
    p = None
    layer =[]
    prev_h = 0
    layer_num = -1
    for i in point_from_file():
        d = i[-1]
        if h > prev_h:
            layer_num += 1
            layer[layer_num] = []
            prev_h = h
        layer[layer_num].append(i)
    #taking one layer
    points = layer[5] #chose a layer to avoid noise from bottom
    dr = 1 # delta radian
    #p = (h,r,d)
    mid_pts = []
    mid_d = []
    for p2,p1,p0 in zip(
        points[0:]     +points[:0],
        points[0+dr:]  +points[:0+dr],
        points[0+2*dr:]+points[:0+2*dr]):
        if p2[2]>= p1[2] and p1[2] =< p[2]: #not cave , dD/dr <= 0:
           mid_pts.append(p1)
           mid_d.append(p1[2])
    #D = d_min +- Ox or Oy
    #Let Oy >= Ox
    l = min(mid_d) #D - Oy
    #2 Oy >= 2 Ox
    Oy_ds =[]
    for i in mid_d:
        Oy_ds.append(i-l)
    Oy = max(Oy_ds)//2
    D_min = l+ Oy
    return D_min

if __name__ == "__main__":
    with open("tmp.asc","w") as f:
        for i in point_from_file():
            #print(i)
            if len(i)==3:
                f.write("%.6f %.6f %.6f\r\n" % i)
    from pc2stl import pc2stl
    pc2stl("tmp.asc")
    #cleanup
    #os.remove("tmp.asc")"""
    
    
    

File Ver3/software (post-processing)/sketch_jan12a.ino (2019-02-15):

/*  3D Scanner controler
 * Recieve steping instruction (rotation:i,height:i)
 * Send Back instruction (rotation:i, height:i, depth:i)
 * 
 * TBD: circula list
 * Tam Yiu Chau 2019
 */
#include <Stepper.h>
#include <VL53L1X.h>
#include <Wire.h>

VL53L1X dS;

Stepper hStep(200,1,2,3,4);
Stepper rStep(200,5,6,7,8);

const int measurePeriod = 50;//(ms)

int cR; //currnet rotation
int cH; //current height
int move_h(int h){
  int delta = h - cH;
  hStep.step(delta);
  cH = h;
  return delta;
}

void move_r(int r){
  int delta = r-cR;
  rStep.step(delta);
  cR = r;
  return delta;
}

int scan(){return 0;}
void setup(){
  Serial.begin(115200);
  Wire.begin();
  Wire.setClock(400000);

  dS.setTimeout(500);
  if (!dS.init()){
    Serial.println("Failed to detect and initialize sensor!");
    return -1;
  }
  dS.setDistanceMode(VL53L1X::Short);
  dS.setMeasurementTimingBudget(measurePeriod*1000);

  dS.startContinuous(measurePeriod);
  return 0;
}
char buf[3*4*8];
void loop(){
  Serial.readBytes(buf,2*4*8);
  int rr,rh,rd;
  sscanf("%d%d",buf,&rh,&rr);
  move_h(rh);
  move_r(rr);
  int d = dS.read();//mm
  sprintf("%d%d%d",buf,rh,rr,rd);
  Serial.write(buf,3*4*8);
}
